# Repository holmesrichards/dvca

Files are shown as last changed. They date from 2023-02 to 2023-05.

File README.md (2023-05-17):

# MFOS Dual VCA

Kosmo format version of the [Music From Outer Space Dual VCA](http://musicfromouterspace.com/analogsynth_new/DUALVCA/DLLVCA001.html) synth module.

Circuit is basically unchanged from the original except:

* Eurorack style power header added, with reversal protection diodes
* Normal connection from 1st VCA output to 2nd VCA input

## Current draw
15 mA +12 V, 15 mA -12 V

## Photos

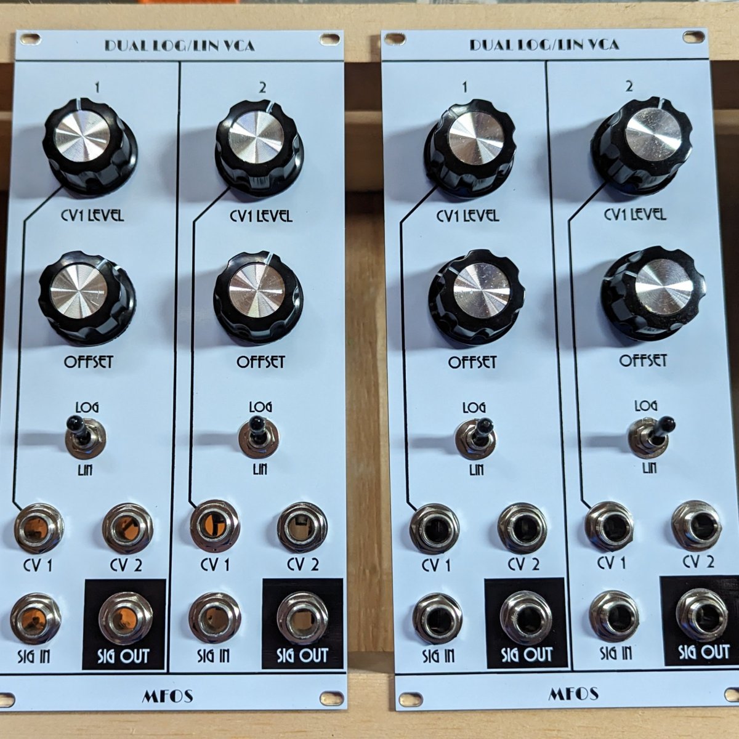
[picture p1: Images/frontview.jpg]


## Documentation

* [Schematic](Docs/dualvca_schematic.pdf)
* PCB layout: [front PCB front](Docs/Layout/dualvca_FrontPCB/dualvca_FrontPCB_front.svg), [front PCB back](Docs/Layout/dualvca_FrontPCB/dualvca_FrontPCB_back.svg), [back PCB front](Docs/Layout/dualvca_BackPCB/dualvca_BackPCB_front.svg), [back PCB back](Docs/Layout/dualvca_BackPCB/dualvca_BackPCB_back.svg)
* [BOM](Docs/BOM/dualvca_bom.md)
<!-- * [Build notes](Docs/build.md) -->
<!-- * [How it works](Docs/howitworks.md) -->
<!--* [Blog post]() -->

## GitHub repository

* [https://github.com/holmesrichards/dvca](https://github.com/holmesrichards/dvca)

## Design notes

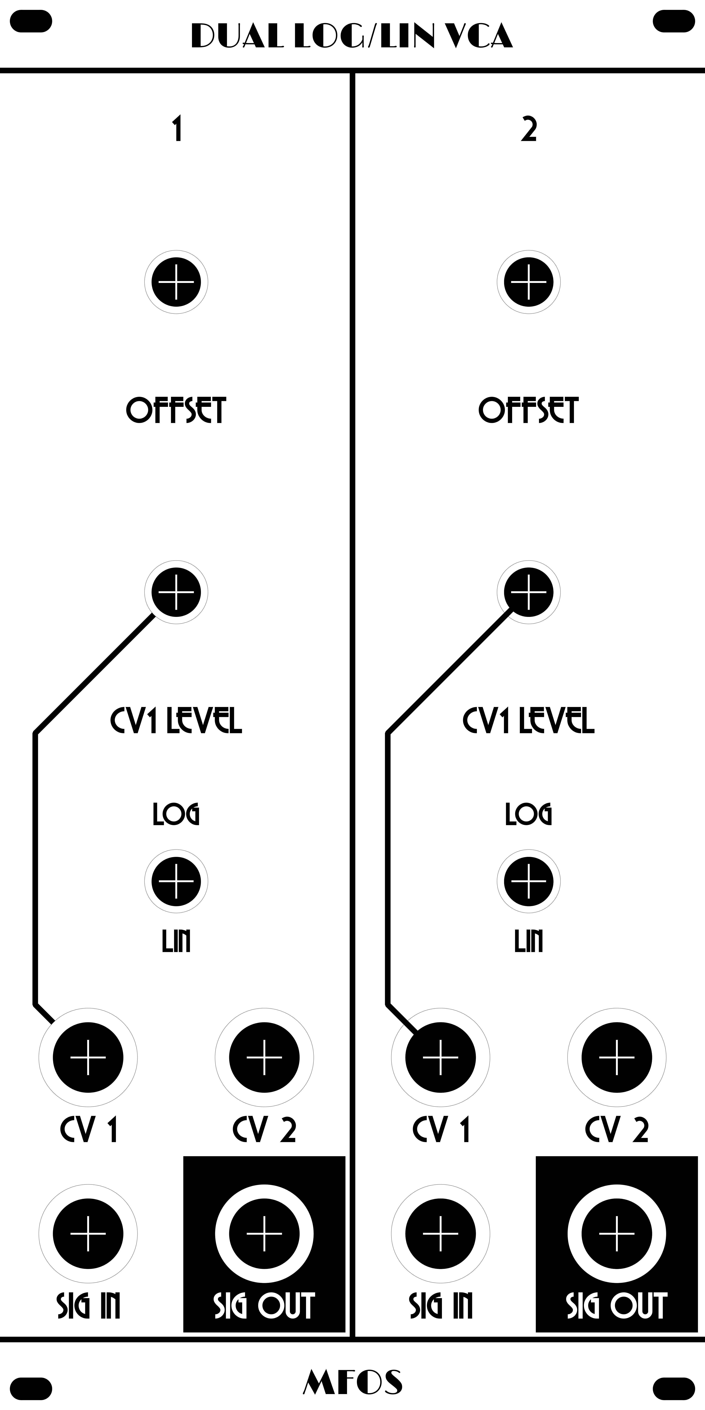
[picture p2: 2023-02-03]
Images/mfos_vca_panel_100_holes.png

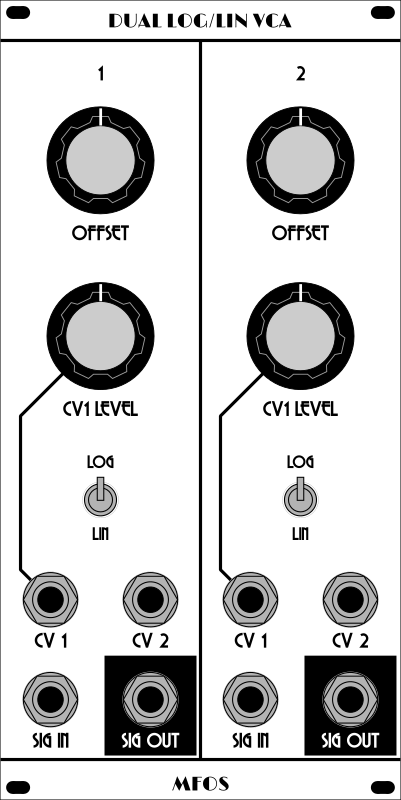
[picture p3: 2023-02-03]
Images/mfos_vca_panel_100.png

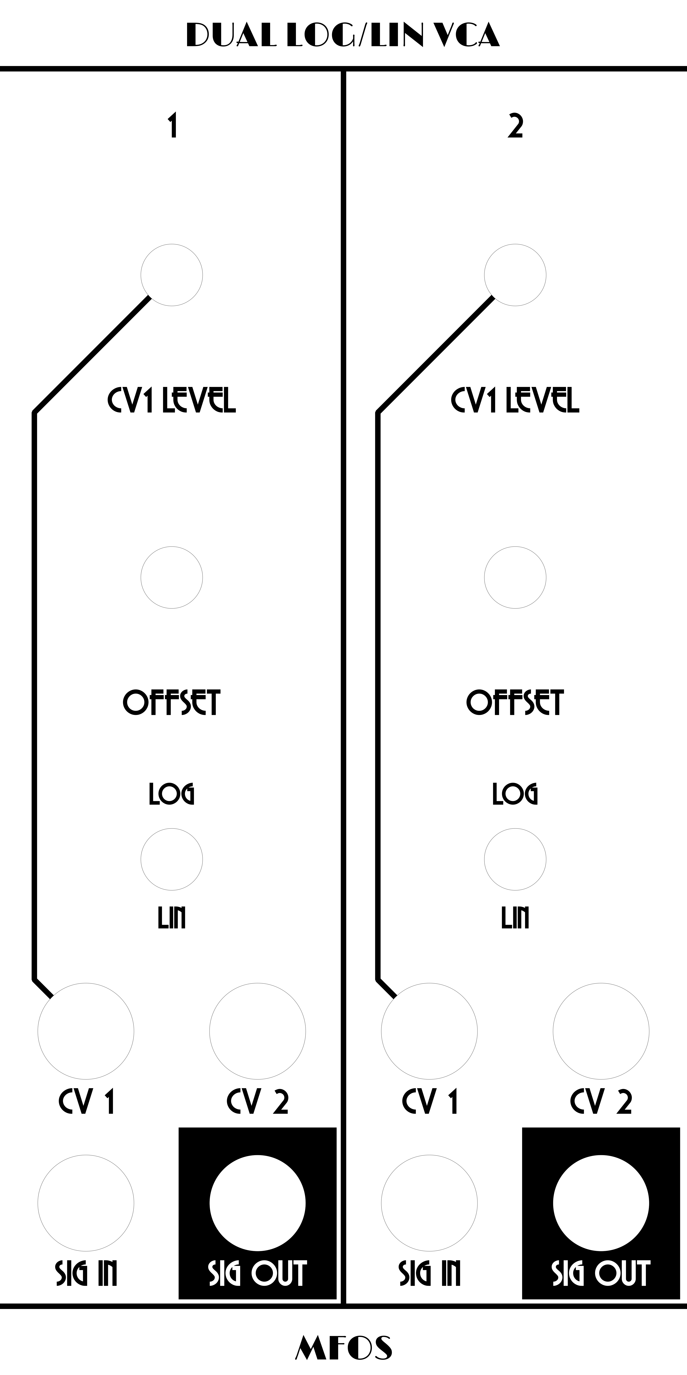
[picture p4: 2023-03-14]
Images/mfos_vca_panel_100_art.png

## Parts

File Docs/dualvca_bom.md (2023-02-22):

# dualvca.kicad_sch BOM

Tue 14 Feb 2023 09:02:56 PM EST

Generated from schematic by Eeschema 7.99.0-unknown-2cc3d8e9bc~165~ubuntu22.04.1

**Component Count:** 87

| Refs | Qty | Component | Description | Manufacturer | Part | Vendor | SKU |
| ----- | --- | ---- | --- | ---- | ---- | ---- | ---- |
| C1, C4 | 2 | 10uF | Electrolytic capacitor, 2.5 mm pitch |  |  | Tayda | A-4349 |
| C2, C3, C5, C6 | 4 | 100nF | Ceramic disc capacitor, 5 mm pitch |  |  | Tayda | A-553 |
| D101, D102 | 2 | 1N5817 | Schottky Barrier Rectifier Diode, DO-41 |  |  | Tayda | A-159 |
| J1, J2, J3, J4, J5, J6, J7 | 7 | AudioJack2 | Audio Jack, 2 Poles (Mono / TS) |  |  | Tayda | A-1121 |
| J8 | 1 | AudioJack2_SwitchT | Audio Jack, 2 Poles (Mono / TS), Switched T Pole (Normalling) |  |  | Tayda | A-1121 |
| J101 | 1 | Conn_01x15 | 2.54 mm pin header, 1x15 positions |  |  |  |  |
| J102 | 1 | Conn_01x15 | 2.54 mm pin socket, 1x15 positions |  |  |  |  |
| J103 | 1 | Synth_power_2x5 | Pin header 2.54 mm 2x5 |  |  | Tayda | A-2939 |
| J104 | 1 | DIP-14 | 14 pin DIP socket |  |  |  |  |
| J105 | 1 | DIP-16 | 16 pin DIP socket |  |  |  |  |
| Q1, Q3 | 2 | 2N3904 | Small Signal NPN Transistor, TO-92 |  |  | Tayda | A-111 |
| Q2, Q4 | 2 | 2N3906 | -0.2A Ic, -40V Vce, Small Signal PNP Transistor, TO-92 |  |  | Tayda | A-117 |
| R1, R2, R4, R5, R11, R13, R19, R23, R24, R26, R27, R33, R36, R40 | 14 | 100k | Resistor |  |  | Tayda |  |
| R3, R7, R25, R29, R37, R101 | 6 | 2k | Resistor |  |  | Tayda |  |
| R6, R28 | 2 | 470R | Resistor |  |  | Tayda |  |
| R8, R15, R30, R35 | 4 | 20k | Resistor |  |  | Tayda |  |
| R9, R31 | 2 | 30k | Resistor |  |  | Tayda |  |
| R14, R34 | 2 | 120k | Resistor |  |  | Tayda |  |
| R16, R38 | 2 | 4.7k | Resistor |  |  | Tayda |  |
| R17, R39 | 2 | 1k | Resistor |  |  | Tayda |  |
| R20, R42 | 2 | 150R | Resistor |  |  | Tayda |  |
| R21, R43 | 2 | 470k | Resistor |  |  | Tayda |  |
| R22, R44 | 2 | 47k | Resistor |  |  | Tayda |  |
| R46, R48 | 2 | 2M | Resistor |  |  | Tayda |  |
| RV10, RV32, RV101, RV102 | 4 | 100k | 9 mm board mount vertical pots (fit these *or* 16 mm) |  |  | Tayda |  |
| RV18, RV41, RV45, RV47 | 4 | 2k | Trim-potentiometer | Bourns | 3296W | Tayda |  |
| RV103, RV104, RV105, RV106 | 4 | 100k | 16 mm board mount vertical pots (fit these *or* 9 mm) |  |  | Tayda |  |
| SW1, SW2 | 2 | SW_SPDT | Switch, single pole double throw |  |  | Tayda | A-3186 |
| U1 | 1 | TL074 | Quad operational amplifier, DIP-14 |  |  | Tayda | A-1138 |
| U2 | 1 | LM13700 | Dual OTA, DIP-16 |  |  | Tayda | A-900 |
| ZKN101, ZKN102, ZKN103, ZKN104 | 4 | Knob_MF-A03 | MF-A03 knob |  |  |  |  |

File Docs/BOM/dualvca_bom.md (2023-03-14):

# dualvca.kicad_sch BOM

Mon 13 Mar 2023 09:42:59 PM EDT

Generated from schematic by Eeschema 7.0.1-3b83917a11~171~ubuntu22.04.1

**Component Count:** 87

| Refs | Qty | Component | Description | Manufacturer | Part | Vendor | SKU |
| ----- | --- | ---- | --- | ---- | ---- | ---- | ---- |
| C1, C4 | 2 | 10uF | Electrolytic capacitor, 2.5 mm pitch |  |  | Tayda | A-4349 |
| C2, C3, C5, C6 | 4 | 100nF | Ceramic disc capacitor, 5 mm pitch |  |  | Tayda | A-553 |
| D101, D102 | 2 | 1N5817 | Schottky Barrier Rectifier Diode, DO-41 |  |  | Tayda | A-159 |
| J1–7 | 7 | AudioJack2 | Audio Jack, 2 Poles (Mono / TS) |  |  | Tayda | A-1121 |
| J8 | 1 | AudioJack2_SwitchT | Audio Jack, 2 Poles (Mono / TS), Switched T Pole (Normalling) |  |  | Tayda | A-1121 |
| J101 | 1 | Conn_01x15 | 2.54 mm pin header, 1x15 positions |  |  |  |  |
| J102 | 1 | Conn_01x15 | 2.54 mm pin socket, 1x15 positions |  |  |  |  |
| J103 | 1 | Synth_power_2x5 | Pin header 2.54 mm 2x5 |  |  | Tayda | A-2939 |
| J104 | 1 | DIP-14 | 14 pin DIP socket |  |  |  |  |
| J105 | 1 | DIP-16 | 16 pin DIP socket |  |  |  |  |
| Q1, Q3 | 2 | 2N3904 | Small Signal NPN Transistor, TO-92 |  |  | Tayda | A-111 |
| Q2, Q4 | 2 | 2N3906 | -0.2A Ic, -40V Vce, Small Signal PNP Transistor, TO-92 |  |  | Tayda | A-117 |
| R1, R2, R4, R5, R11, R13, R19, R23, R24, R26, R27, R33, R36, R40 | 14 | 100k | Resistor |  |  | Tayda |  |
| R3, R7, R25, R29, R37, R101 | 6 | 2k | Resistor |  |  | Tayda |  |
| R6, R28 | 2 | 470R | Resistor |  |  | Tayda |  |
| R8, R15, R30, R35 | 4 | 20k | Resistor |  |  | Tayda |  |
| R9, R31 | 2 | 30k | Resistor |  |  | Tayda |  |
| R14, R34 | 2 | 120k | Resistor |  |  | Tayda |  |
| R16, R38 | 2 | 4.7k | Resistor |  |  | Tayda |  |
| R17, R39 | 2 | 1k | Resistor |  |  | Tayda |  |
| R20, R42 | 2 | 150R | Resistor |  |  | Tayda |  |
| R21, R43 | 2 | 470k | Resistor |  |  | Tayda |  |
| R22, R44 | 2 | 47k | Resistor |  |  | Tayda |  |
| R46, R48 | 2 | 2M | Resistor |  |  | Tayda |  |
| RV10, RV32, RV101, RV102 | 4 | 100k | 9 mm board mount vertical pots (fit these *or* 16 mm) |  |  | Tayda |  |
| RV18, RV41, RV45, RV47 | 4 | 2k | Trim-potentiometer | Bourns | 3296W | Tayda |  |
| RV103–106 | 4 | 100k | 16 mm board mount vertical pots (fit these *or* 9 mm) |  |  | Tayda |  |
| SW1, SW2 | 2 | SW_SPDT | Switch, single pole double throw |  |  | Tayda | A-3186 |
| U1 | 1 | TL074 | Quad operational amplifier, DIP-14 |  |  | Tayda | A-1138 |
| U2 | 1 | LM13700 | Dual OTA, DIP-16 |  |  | Tayda | A-900 |
| ZKN101–104 | 4 | Knob_MF-A03 | MF-A03 knob |  |  |  |  |

## Resistors in color band order
|Value|Qty|Refs|
|----|----|----|
|1k|2|R17, R39|
|100k|14|R1, R2, R4, R5, R11, R13, R19, R23, R24, R26, R27, R33, R36, R40|
|120k|2|R14, R34|
|150R|2|R20, R42|
|2k|6|R3, R7, R25, R29, R37, R101|
|20k|4|R8, R15, R30, R35|
|2M|2|R46, R48|
|30k|2|R9, R31|
|470R|2|R6, R28|
|4.7k|2|R16, R38|
|47k|2|R22, R44|
|470k|2|R21, R43|

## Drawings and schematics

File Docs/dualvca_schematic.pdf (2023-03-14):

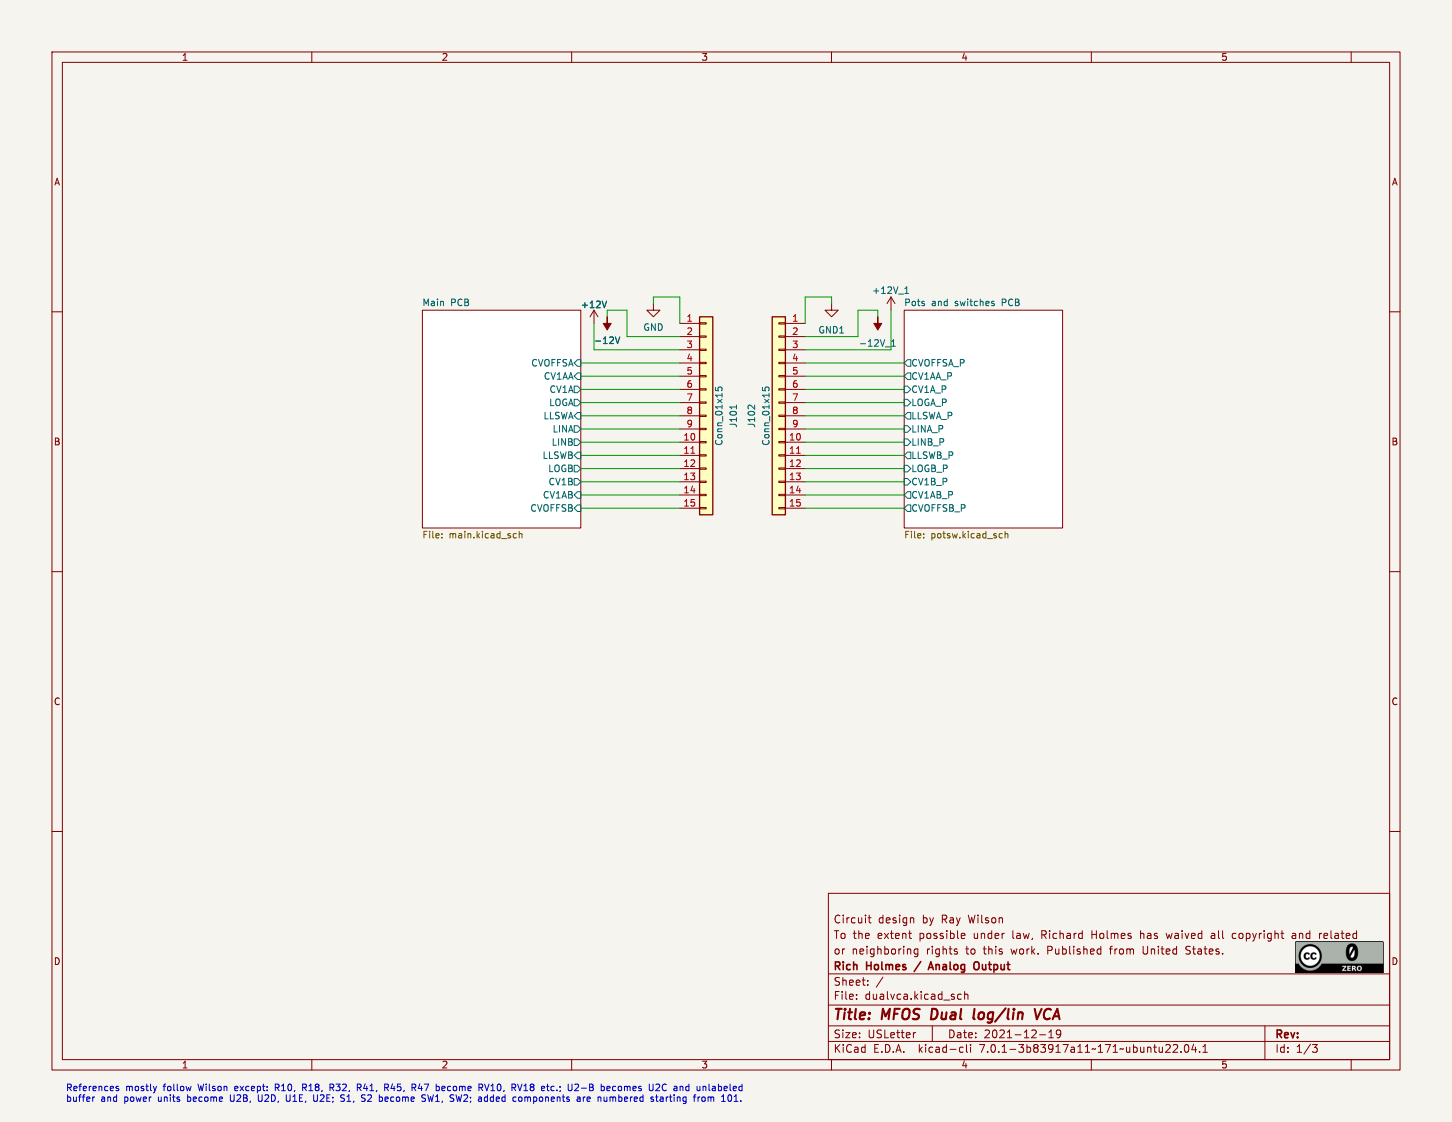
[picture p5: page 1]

LLSWA CV1B CVOFFSB CV1AB CV1AA CV1A CVOFFSA Main PCB

Pots and switches PCB
LINB_P CV1B_P CV1AB_P CV1AA_P CV1A_P CVOFFSA_P

References mostly follow Wilson except: R10, R18, R32, R41, R45, R47 become RV10, RV18 etc.; U2-B becomes U2C and unlabeled

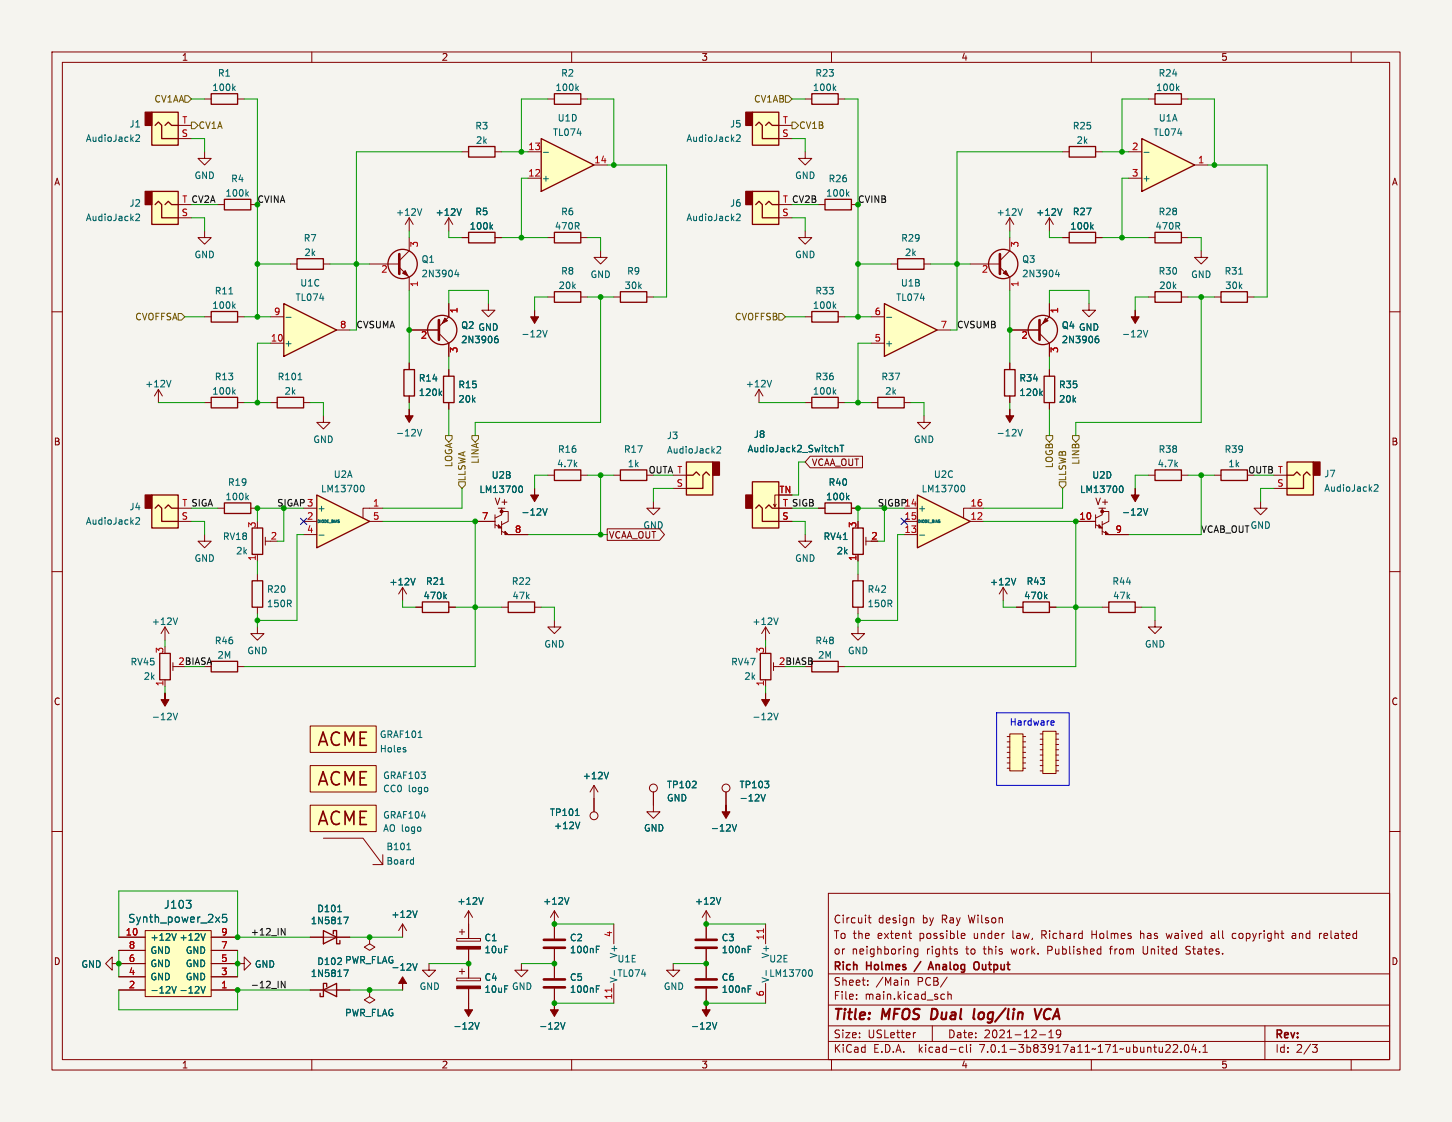
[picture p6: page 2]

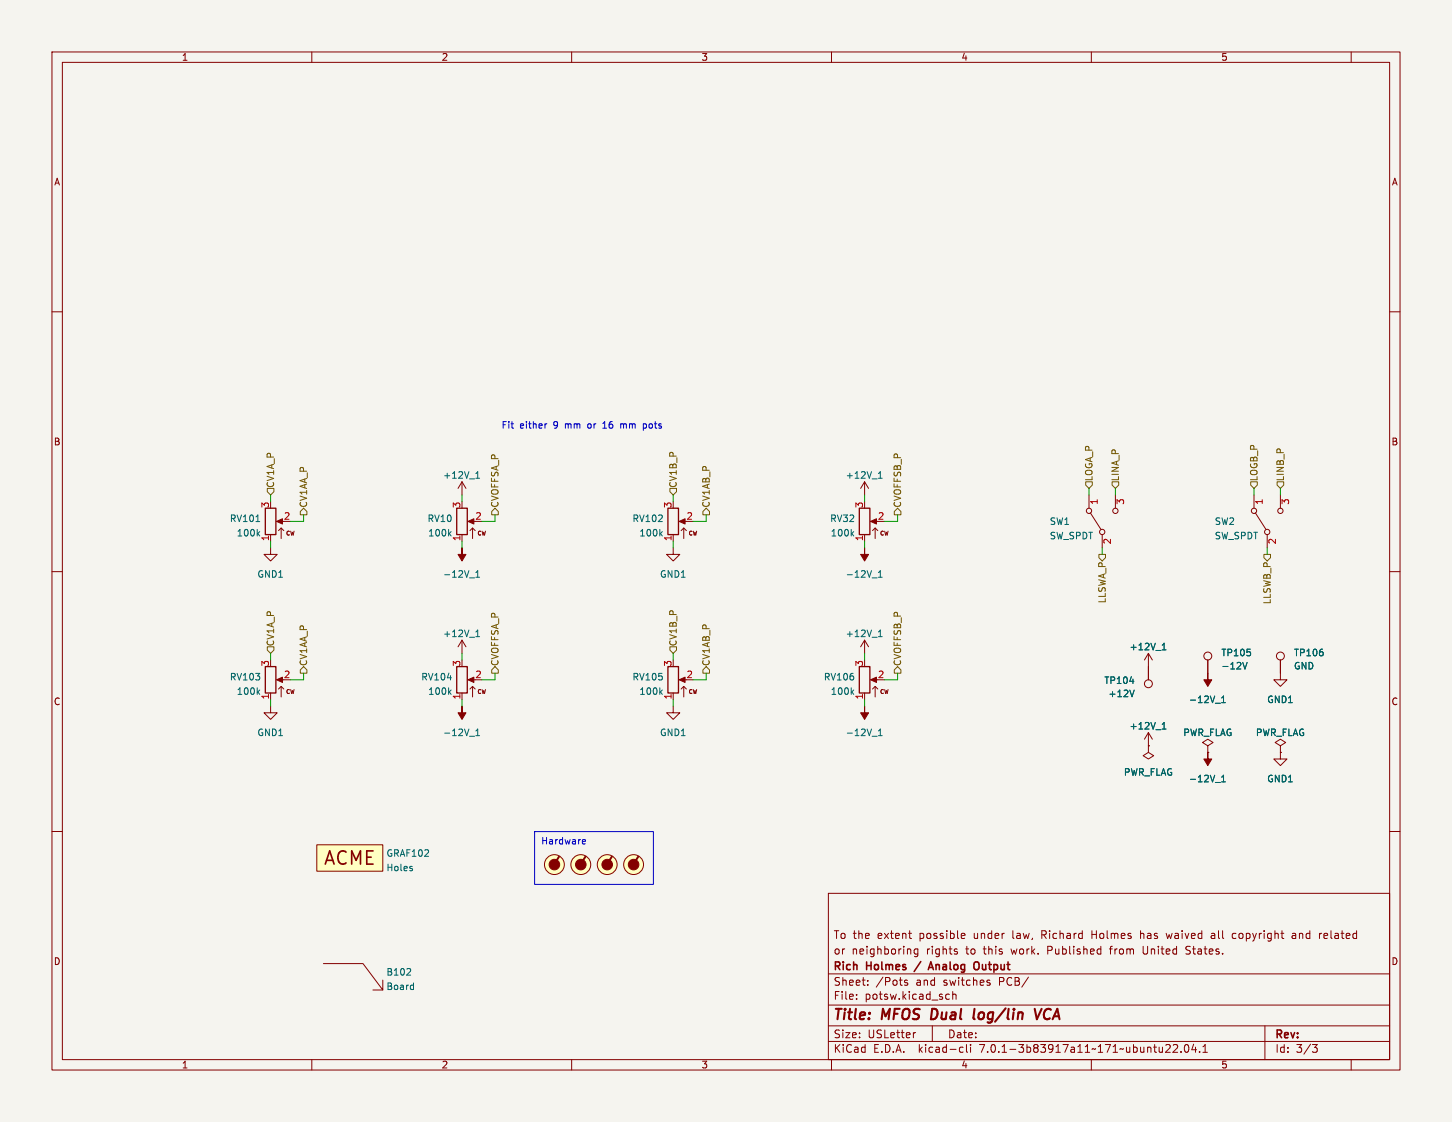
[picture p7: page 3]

Fit either 9 mm or 16 mm pots

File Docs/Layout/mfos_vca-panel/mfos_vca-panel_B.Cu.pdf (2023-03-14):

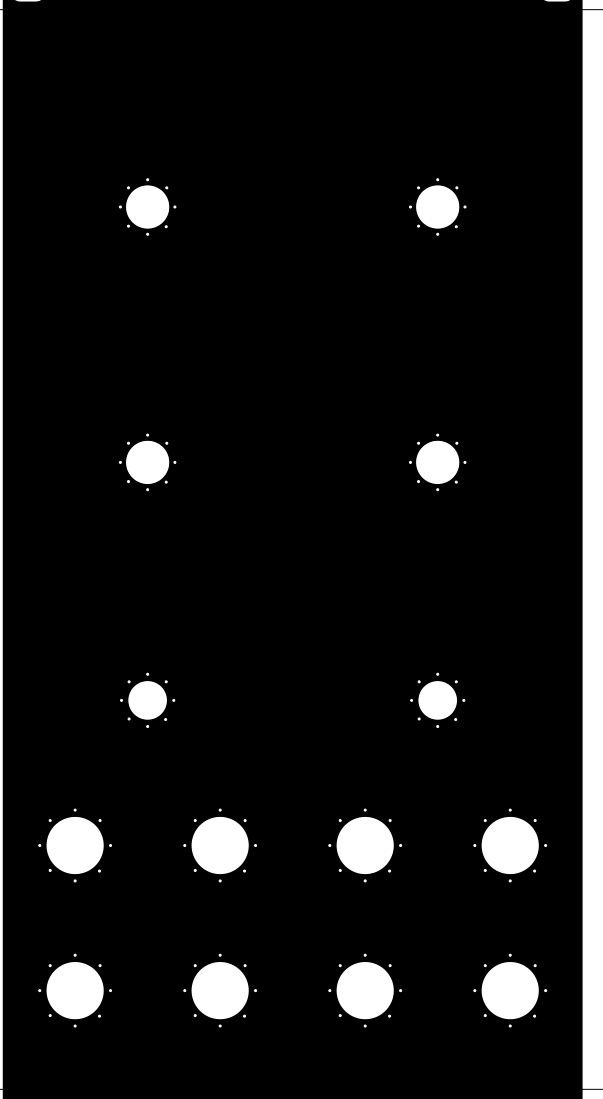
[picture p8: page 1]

Id: 1/1 Title: File: mfos_vca-panel.kicad_pcb Sheet:

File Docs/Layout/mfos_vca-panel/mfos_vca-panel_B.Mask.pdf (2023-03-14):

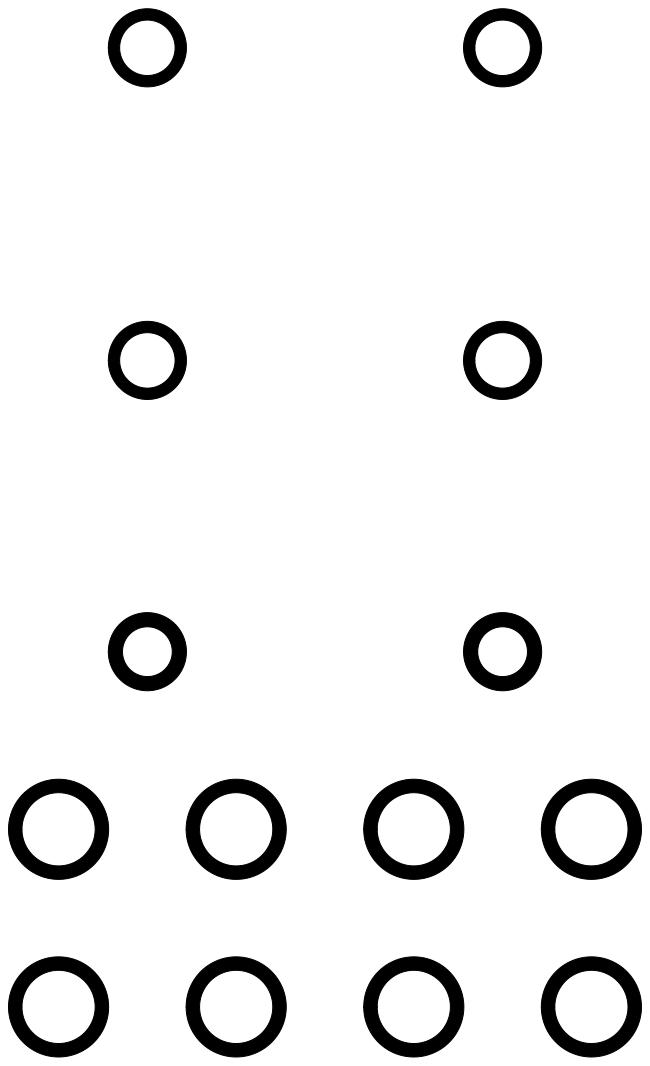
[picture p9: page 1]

Id: 1/1 Title: File: mfos_vca-panel.kicad_pcb Sheet:

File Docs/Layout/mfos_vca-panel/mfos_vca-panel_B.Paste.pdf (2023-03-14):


Id: 1/1 Title: File: mfos_vca-panel.kicad_pcb Sheet:

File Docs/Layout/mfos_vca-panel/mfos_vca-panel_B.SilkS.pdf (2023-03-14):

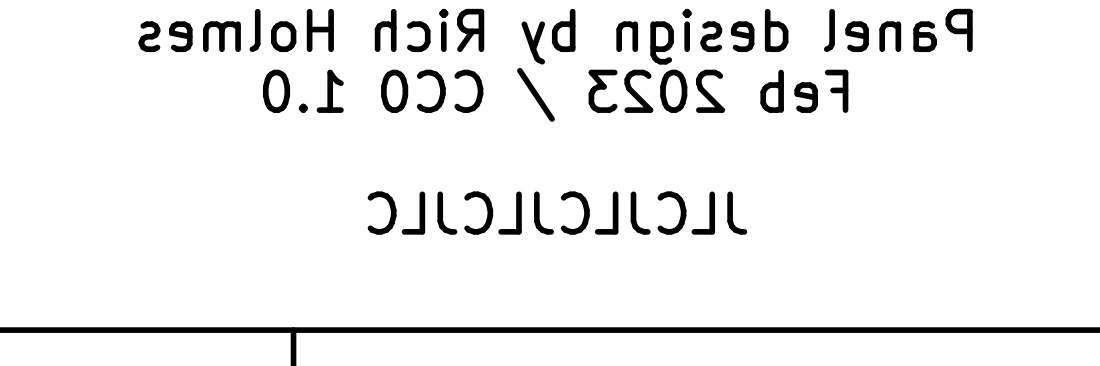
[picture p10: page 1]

Id: 1/1 Title: File: mfos_vca-panel.kicad_pcb Sheet: Panel design by Rich Holmes Feb 2023 / CC0 1.0

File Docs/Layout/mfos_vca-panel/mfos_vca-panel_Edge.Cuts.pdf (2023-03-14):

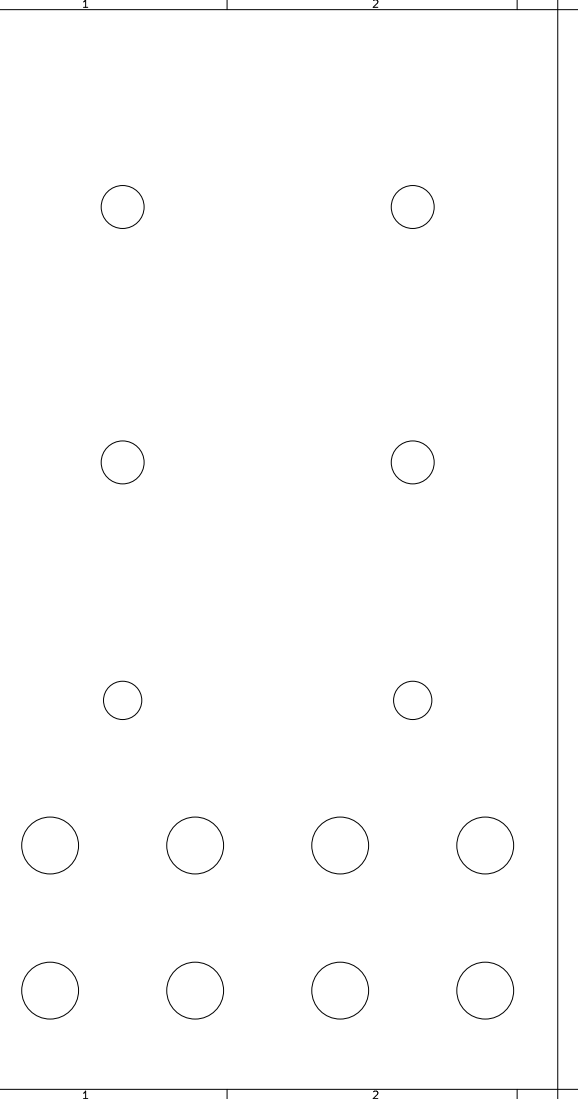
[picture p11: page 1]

Id: 1/1 Title: File: mfos_vca-panel.kicad_pcb Sheet:

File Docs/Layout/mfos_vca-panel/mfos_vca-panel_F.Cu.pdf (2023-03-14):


Id: 1/1 Title: File: mfos_vca-panel.kicad_pcb Sheet:

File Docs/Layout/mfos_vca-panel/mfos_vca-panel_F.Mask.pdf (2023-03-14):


Id: 1/1 Title: File: mfos_vca-panel.kicad_pcb Sheet:

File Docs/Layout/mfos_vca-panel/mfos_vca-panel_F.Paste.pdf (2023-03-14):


Id: 1/1 Title: File: mfos_vca-panel.kicad_pcb Sheet:

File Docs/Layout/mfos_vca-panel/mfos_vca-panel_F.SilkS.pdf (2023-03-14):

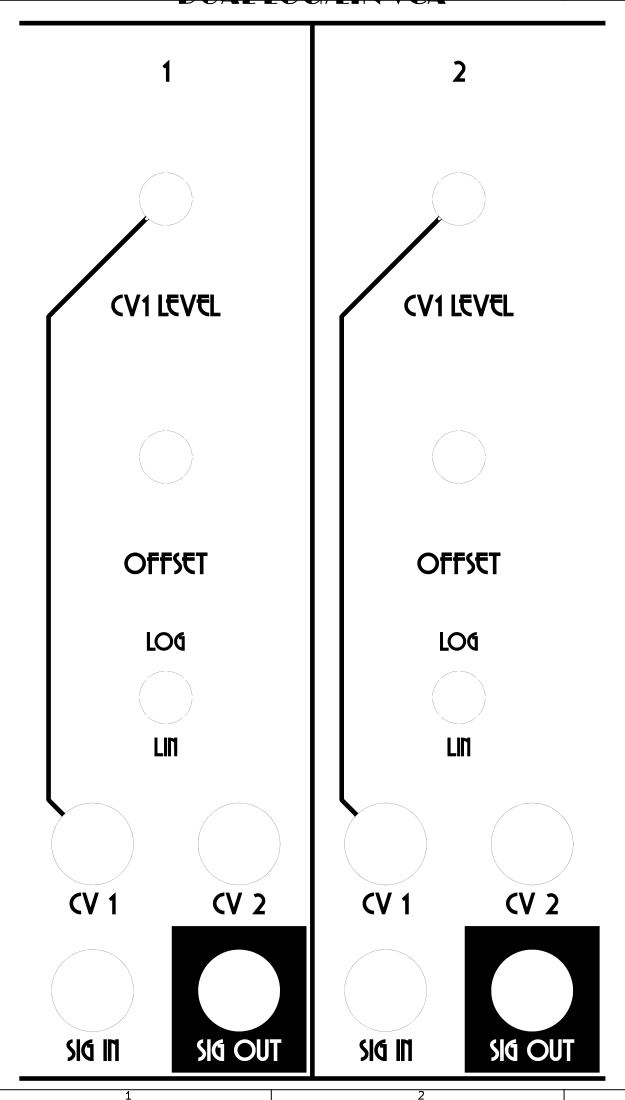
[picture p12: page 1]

Id: 1/1 Title: File: mfos_vca-panel.kicad_pcb Sheet:

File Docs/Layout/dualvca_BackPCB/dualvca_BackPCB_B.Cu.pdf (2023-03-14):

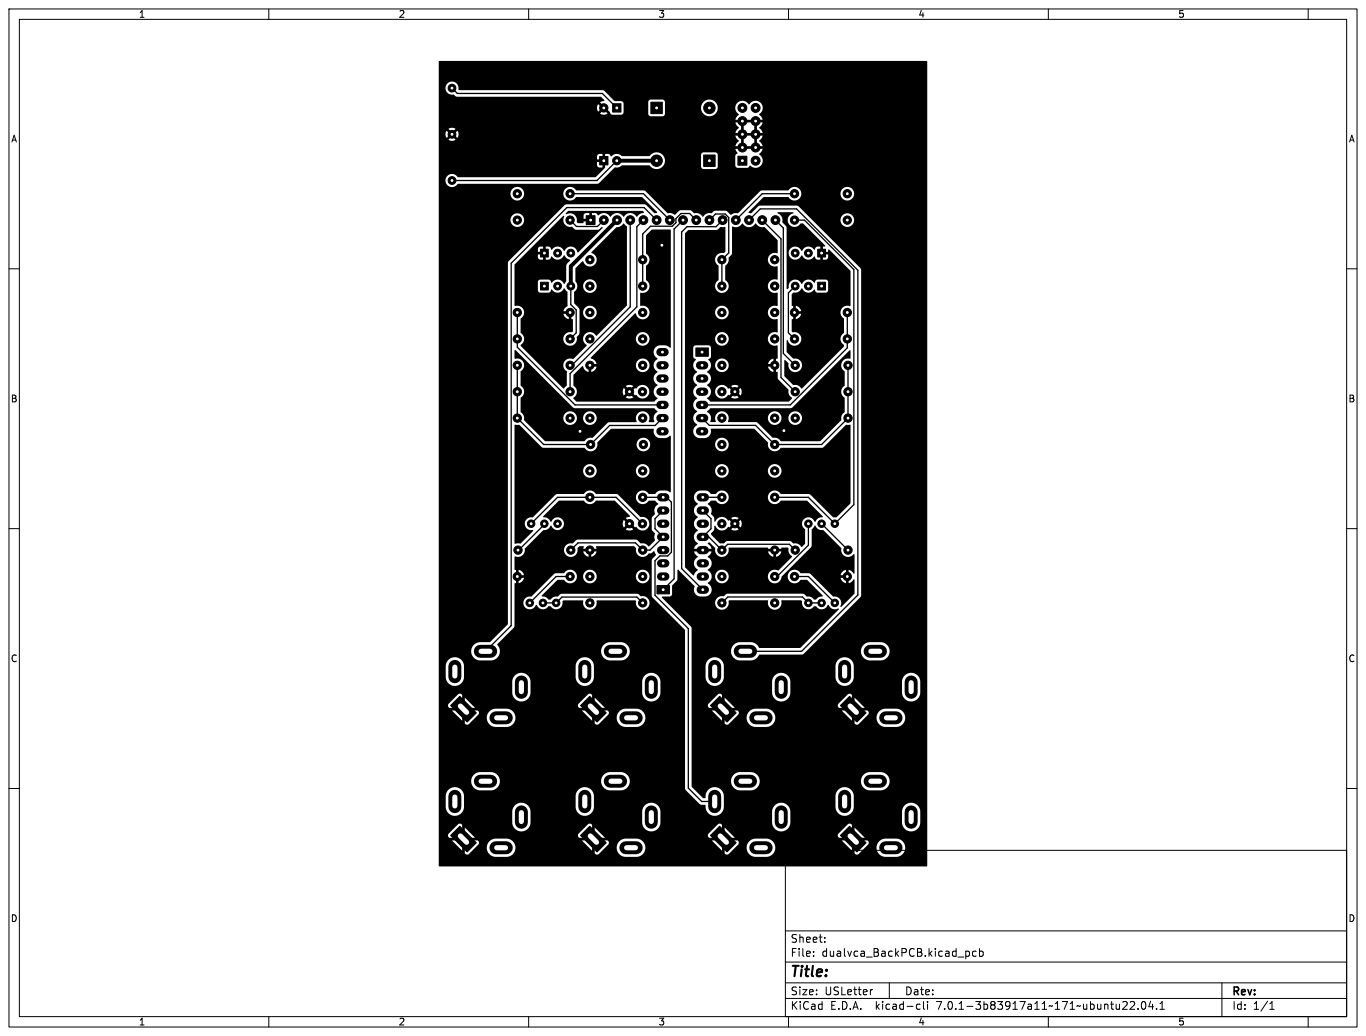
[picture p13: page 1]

Id: 1/1 Title: File: dualvca_BackPCB.kicad_pcb Sheet:

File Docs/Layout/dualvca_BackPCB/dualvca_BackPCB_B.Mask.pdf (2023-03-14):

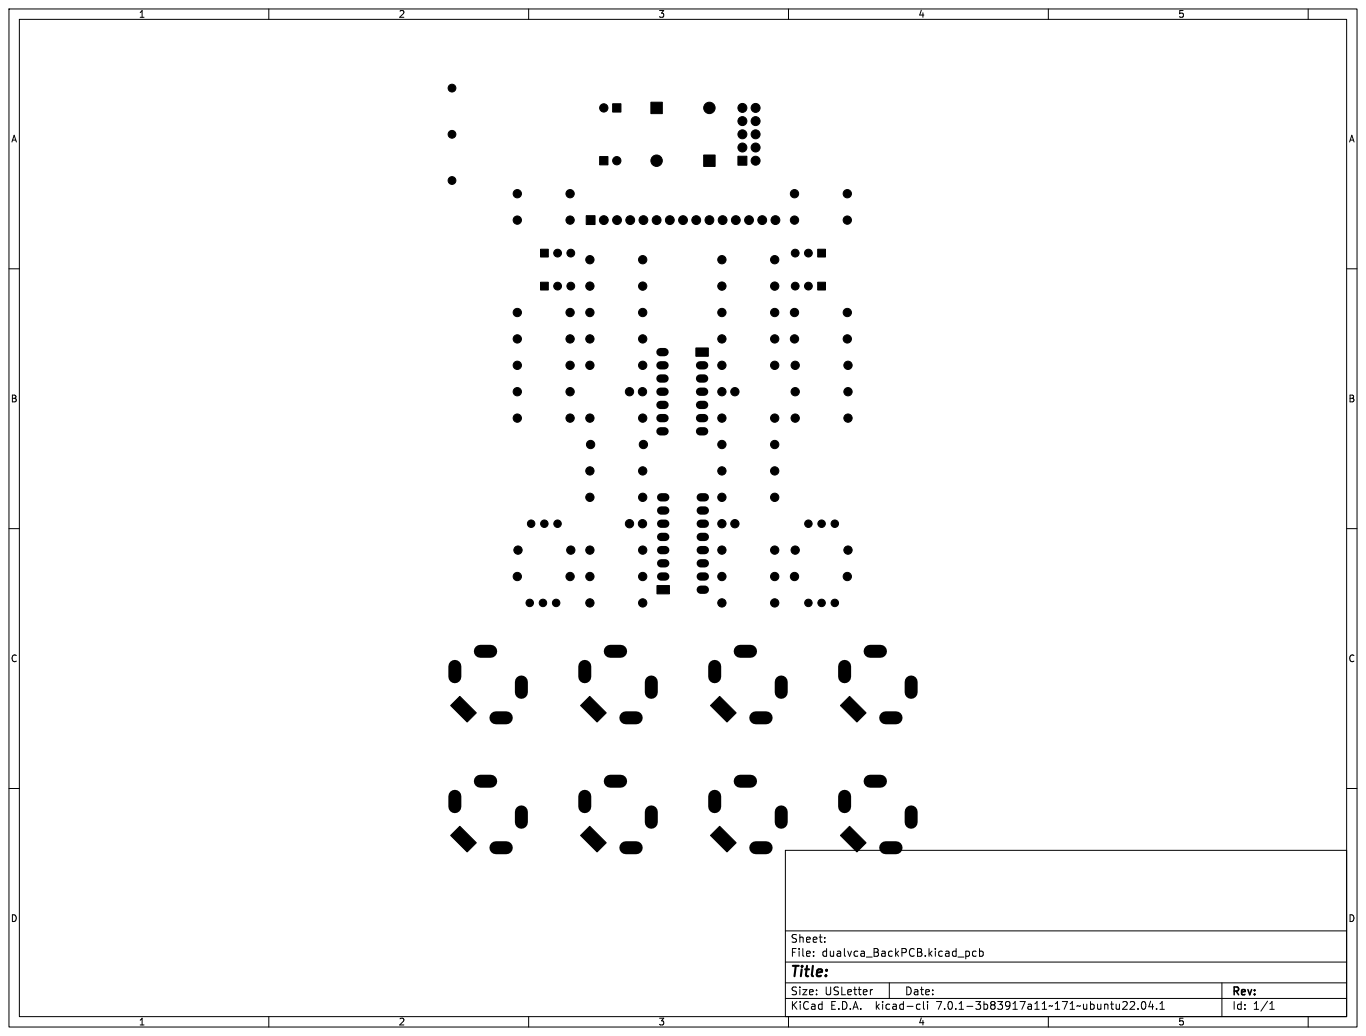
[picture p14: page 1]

Id: 1/1 Title: File: dualvca_BackPCB.kicad_pcb Sheet:

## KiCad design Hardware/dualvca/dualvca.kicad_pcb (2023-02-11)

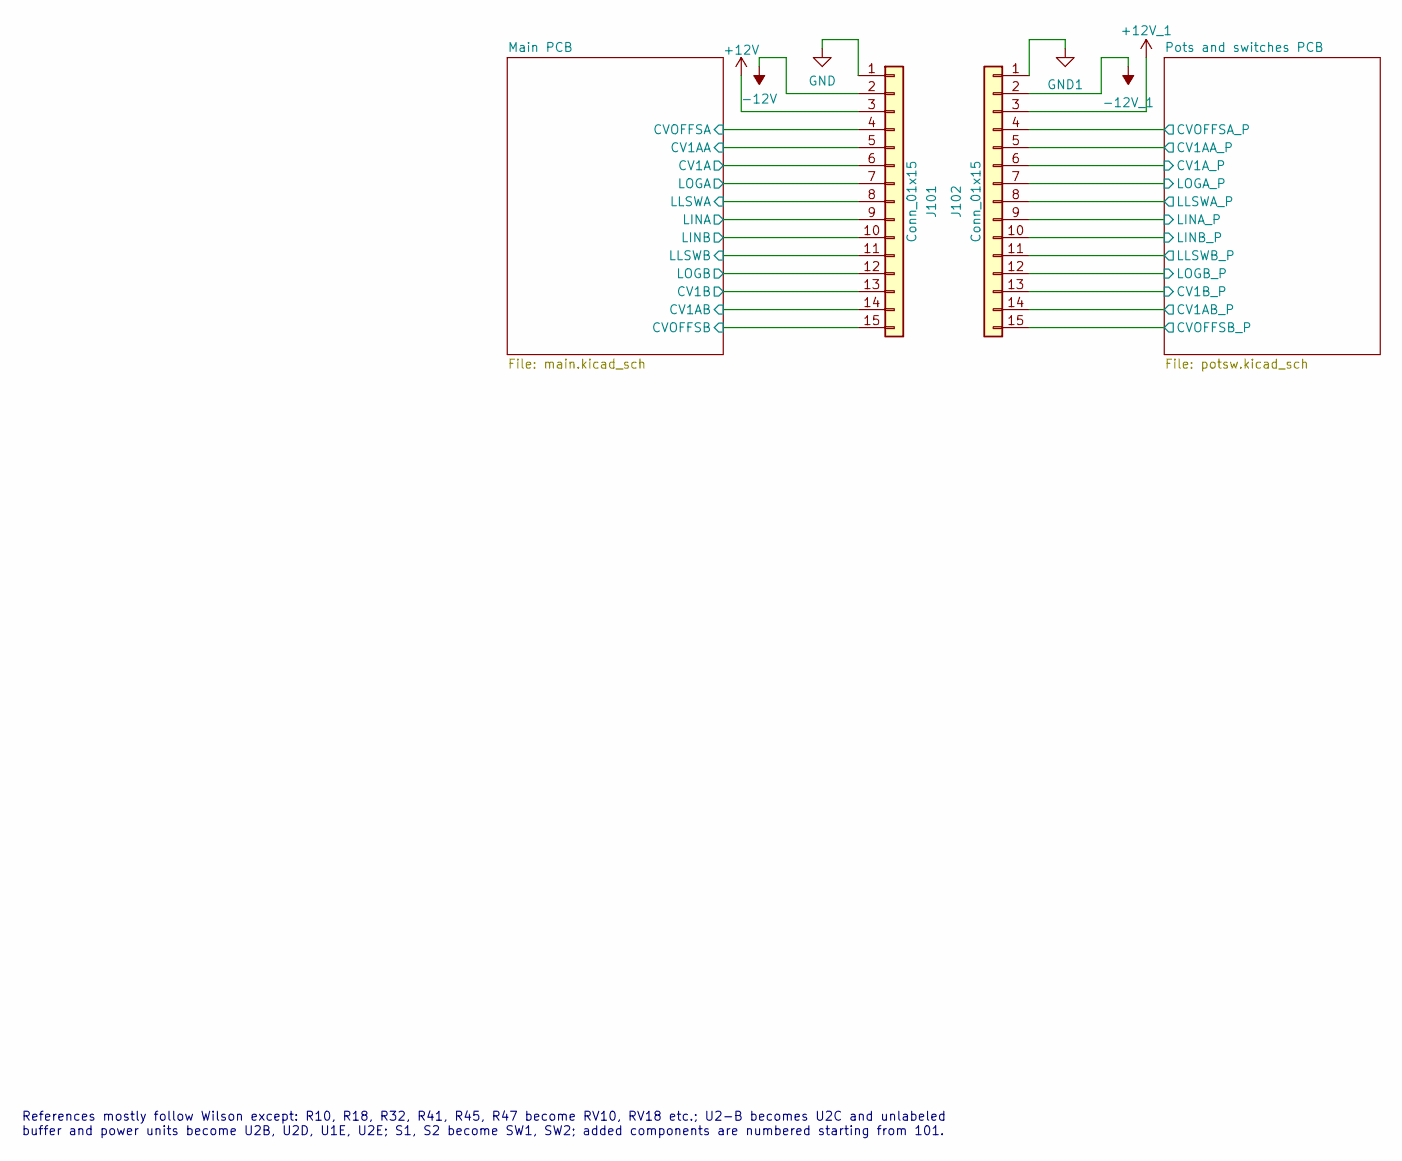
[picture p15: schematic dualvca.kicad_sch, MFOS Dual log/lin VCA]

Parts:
J101: Conn_01x15; PinHeader_1x15_P2.54mm_Vertical
J102: Conn_01x15; PinSocket_1x15_P2.54mm_Vertical

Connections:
+12V: J101.3; also elsewhere on the board
+12V_1: J102.3; also elsewhere on the board
-12V: J101.2; also elsewhere on the board
-12V_1: J102.2; also elsewhere on the board
/Main PCB/CV1A: J101.6; also elsewhere on the board
/Main PCB/CV1AA: J101.5; also elsewhere on the board
/Main PCB/CV1AB: J101.14; also elsewhere on the board
/Main PCB/CV1B: J101.13; also elsewhere on the board
/Main PCB/CVOFFSA: J101.4; also elsewhere on the board
/Main PCB/CVOFFSB: J101.15; also elsewhere on the board
/Main PCB/LINA: J101.9; also elsewhere on the board
/Main PCB/LINB: J101.10; also elsewhere on the board
/Main PCB/LLSWA: J101.8; also elsewhere on the board
/Main PCB/LLSWB: J101.11; also elsewhere on the board
/Main PCB/LOGA: J101.7; also elsewhere on the board
/Main PCB/LOGB: J101.12; also elsewhere on the board
/Pots and switches PCB/CV1AA_P: J102.5; also elsewhere on the board
/Pots and switches PCB/CV1AB_P: J102.14; also elsewhere on the board
/Pots and switches PCB/CV1A_P: J102.6; also elsewhere on the board
/Pots and switches PCB/CV1B_P: J102.13; also elsewhere on the board
/Pots and switches PCB/CVOFFSA_P: J102.4; also elsewhere on the board
/Pots and switches PCB/CVOFFSB_P: J102.15; also elsewhere on the board
/Pots and switches PCB/LINA_P: J102.9; also elsewhere on the board
/Pots and switches PCB/LINB_P: J102.10; also elsewhere on the board
/Pots and switches PCB/LLSWA_P: J102.8; also elsewhere on the board
/Pots and switches PCB/LLSWB_P: J102.11; also elsewhere on the board
/Pots and switches PCB/LOGA_P: J102.7; also elsewhere on the board
/Pots and switches PCB/LOGB_P: J102.12; also elsewhere on the board
GND: J101.1; also elsewhere on the board
GND1: J102.1; also elsewhere on the board

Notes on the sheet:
References mostly follow Wilson except: R10, R18, R32, R41, R45, R47 become RV10, RV18 etc.; U2-B becomes U2C and unlabeled buffer and power units become U2B, U2D, U1E, U2E; S1, S2 become SW1, SW2; added components are numbered starting from 101.

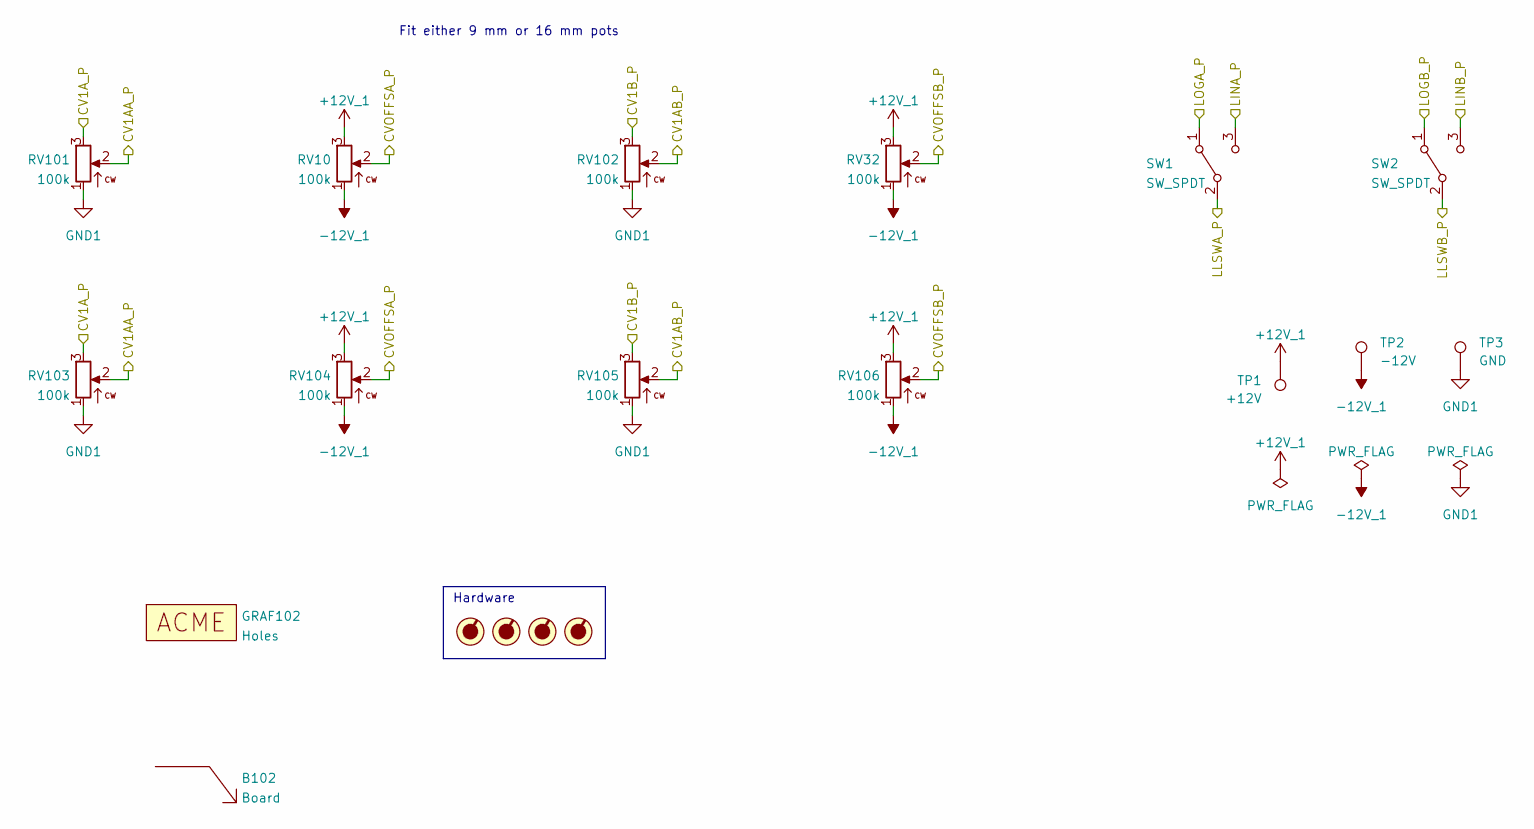
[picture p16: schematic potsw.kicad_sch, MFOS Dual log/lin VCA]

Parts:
B102: Board; Board_Marker
GRAF102: Holes; mfos_vca_panel_100_holes
RV10, RV32, RV101, RV102: 100k; Potentiometer_Alpha_RD901F-40-00D_Single_Vertical_centered
RV103, RV104, RV105, RV106: 100k; Potentiometer_Alpha_16mm_Single_Vertical
SW1, SW2: SW_SPDT; SPDT-toggle-switch-1M-series
TP1: +12V; TestPoint_THTPad_D1.5mm_Drill0.7mm
TP2: -12V; TestPoint_THTPad_D1.5mm_Drill0.7mm
TP3: GND; TestPoint_THTPad_D1.5mm_Drill0.7mm
ZKN101, ZKN102, ZKN103, ZKN104: Knob_MF-A03

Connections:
+12V_1: RV10.3, RV32.3, RV104.3, RV106.3; also elsewhere on the board
-12V_1: RV10.1, RV32.1, RV104.1, RV106.1; also elsewhere on the board
/Pots and switches PCB/CV1AA_P: RV101.2, RV103.2; also elsewhere on the board
/Pots and switches PCB/CV1AB_P: RV102.2, RV105.2; also elsewhere on the board
/Pots and switches PCB/CV1A_P: RV101.3, RV103.3; also elsewhere on the board
/Pots and switches PCB/CV1B_P: RV102.3, RV105.3; also elsewhere on the board
/Pots and switches PCB/CVOFFSA_P: RV10.2, RV104.2; also elsewhere on the board
/Pots and switches PCB/CVOFFSB_P: RV32.2, RV106.2; also elsewhere on the board
/Pots and switches PCB/LINA_P: SW1.3 (C); also elsewhere on the board
/Pots and switches PCB/LINB_P: SW2.3 (C); also elsewhere on the board
/Pots and switches PCB/LLSWA_P: SW1.2 (B); also elsewhere on the board
/Pots and switches PCB/LLSWB_P: SW2.2 (B); also elsewhere on the board
/Pots and switches PCB/LOGA_P: SW1.1 (A); also elsewhere on the board
/Pots and switches PCB/LOGB_P: SW2.1 (A); also elsewhere on the board
GND1: RV101.1, RV102.1, RV103.1, RV105.1; also elsewhere on the board

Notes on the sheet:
Fit either 9 mm or 16 mm pots
Hardware

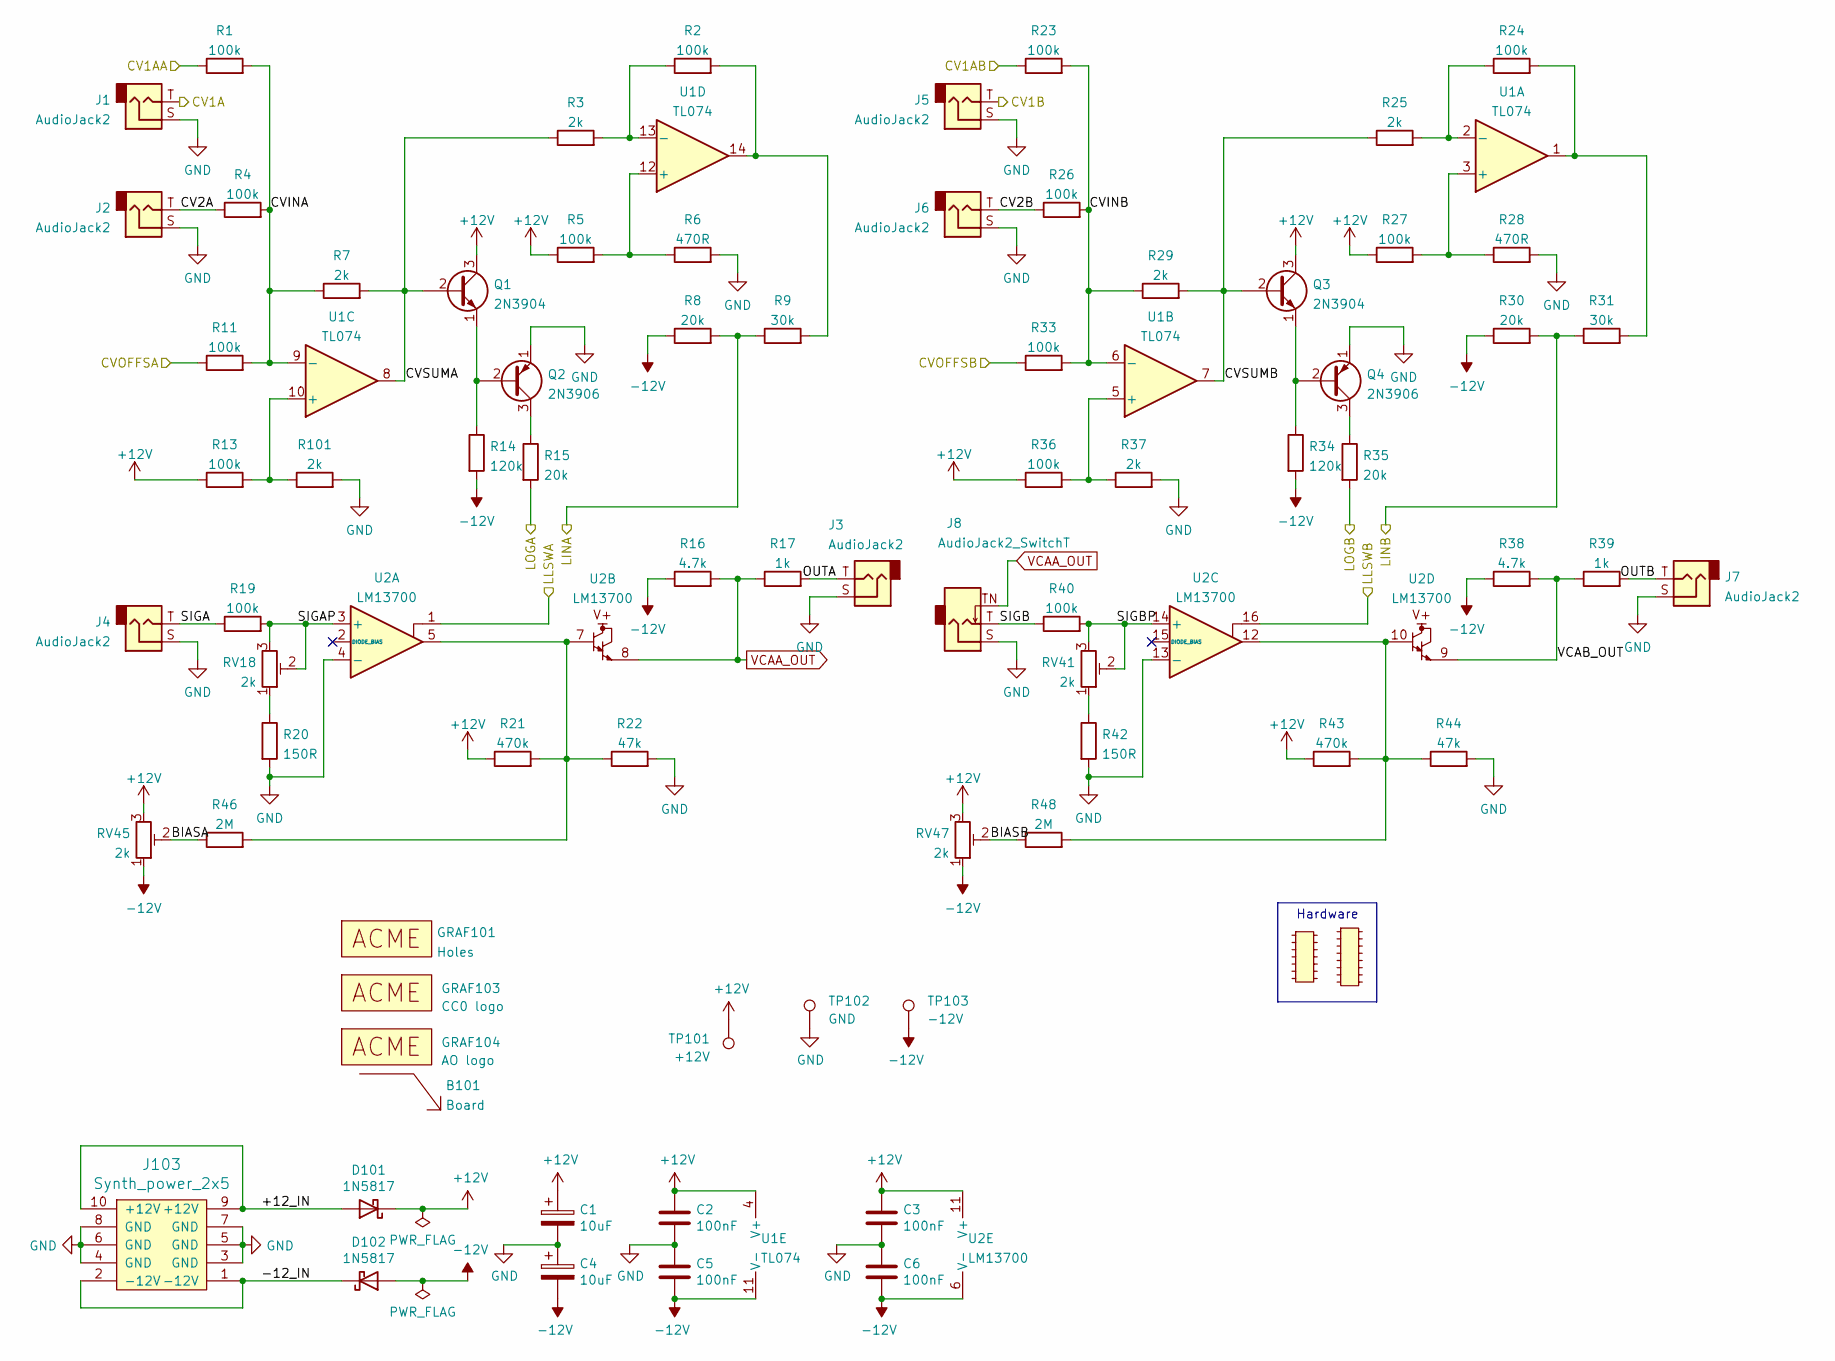
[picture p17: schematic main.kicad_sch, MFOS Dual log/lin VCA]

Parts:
B101: Board; Board_Marker
C1, C4: 10uF; CP_Radial_D6.3mm_P2.50mm
C2, C3, C5, C6: 100nF; C_Disc_D3.0mm_W1.6mm_P2.50mm
D101, D102: 1N5817; D_DO-41_SOD81_P10.16mm_Horizontal
GRAF101: Holes; mfos_vca_panel_100_holes
GRAF103: CC0 logo; CC0_logo
GRAF104: AO logo; analogoutput
J1, J2, J3, J4, J5, J6, J7: AudioJack2; Jack_6.35mm_PJ_629HAN_slots
J8: AudioJack2_SwitchT; Jack_6.35mm_PJ_629HAN_slots
J103: Synth_power_2x5; Power_Header
J104: DIP-14
J105: DIP-16
Q1, Q3: 2N3904; TO-92_Inline_Wide
Q2, Q4: 2N3906; TO-92_Inline_Wide
R1, R2, R4, R5, R11, R13, R19, R23, R24, R26, R27, R33, R36, R40: 100k; R_Axial_DIN0207_L6.3mm_D2.5mm_P10.16mm_Horizontal
R3, R7, R25, R29, R37, R101: 2k; R_Axial_DIN0207_L6.3mm_D2.5mm_P10.16mm_Horizontal
R6, R28: 470R; R_Axial_DIN0207_L6.3mm_D2.5mm_P10.16mm_Horizontal
R8, R15, R30, R35: 20k; R_Axial_DIN0207_L6.3mm_D2.5mm_P10.16mm_Horizontal
R9, R31: 30k; R_Axial_DIN0207_L6.3mm_D2.5mm_P10.16mm_Horizontal
R14, R34: 120k; R_Axial_DIN0207_L6.3mm_D2.5mm_P10.16mm_Horizontal
R16, R38: 4.7k; R_Axial_DIN0207_L6.3mm_D2.5mm_P10.16mm_Horizontal
R17, R39: 1k; R_Axial_DIN0207_L6.3mm_D2.5mm_P10.16mm_Horizontal
R20, R42: 150R; R_Axial_DIN0207_L6.3mm_D2.5mm_P10.16mm_Horizontal
R21, R43: 470k; R_Axial_DIN0207_L6.3mm_D2.5mm_P10.16mm_Horizontal
R22, R44: 47k; R_Axial_DIN0207_L6.3mm_D2.5mm_P10.16mm_Horizontal
R46, R48: 2M; R_Axial_DIN0207_L6.3mm_D2.5mm_P10.16mm_Horizontal
RV18, RV41, RV45, RV47: 2k; Potentiometer_Bourns_3296W_Vertical_standard; Part 3296W
TP101: +12V; TestPoint_THTPad_D1.5mm_Drill0.7mm
TP102: GND; TestPoint_THTPad_D1.5mm_Drill0.7mm
TP103: -12V; TestPoint_THTPad_D1.5mm_Drill0.7mm
U1: TL074; DIP-14_W7.62mm_Socket_LongPads
U2: LM13700; DIP-16_W7.62mm_Socket_LongPads

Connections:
+12V: C1.1, C2.1, C3.1, D101.1 (K), Q1.3 (C), Q3.3 (C), R5.1, R13.1, R21.1, R27.1, R36.1, R43.1, RV45.3, RV47.3, TP101.1, U1.4 (V+), U2.11 (V+); also elsewhere on the board
-12V: C4.2, C5.2, C6.2, D102.2 (A), R8.1, R14.2, R16.1, R30.1, R34.2, R38.1, RV45.1, RV47.1, TP103.1, U1.11 (V-), U2.6 (V-); also elsewhere on the board
/Main PCB/+12_IN: D101.2 (A), J103.9 (+12V), J103.10 (+12V)
/Main PCB/-12_IN: D102.1 (K), J103.1 (-12V), J103.2 (-12V)
/Main PCB/BIASA: R46.1, RV45.2
/Main PCB/BIASB: R48.1, RV47.2
/Main PCB/CV1A: J1.T; also elsewhere on the board
/Main PCB/CV1AA: R1.1; also elsewhere on the board
/Main PCB/CV1AB: R23.1; also elsewhere on the board
/Main PCB/CV1B: J5.T; also elsewhere on the board
/Main PCB/CV2A: J2.T, R4.1
/Main PCB/CV2B: J6.T, R26.1
/Main PCB/CVINA: R1.2, R4.2, R7.1, R11.2, U1.9 (-)
/Main PCB/CVINB: R23.2, R26.2, R29.1, R33.2, U1.6 (-)
/Main PCB/CVOFFSA: R11.1; also elsewhere on the board
/Main PCB/CVOFFSB: R33.1; also elsewhere on the board
/Main PCB/CVSUMA: Q1.2 (B), R3.1, R7.2, U1.8
/Main PCB/CVSUMB: Q3.2 (B), R25.1, R29.2, U1.7
/Main PCB/LINA: R8.2, R9.1; also elsewhere on the board
/Main PCB/LINB: R30.2, R31.1; also elsewhere on the board
/Main PCB/LLSWA: U2.1; also elsewhere on the board
/Main PCB/LLSWB: U2.16; also elsewhere on the board
/Main PCB/LOGA: R15.2; also elsewhere on the board
/Main PCB/LOGB: R35.2; also elsewhere on the board
/Main PCB/OUTA: J3.T, R17.2
/Main PCB/OUTB: J7.T, R39.2
/Main PCB/SIGA: J4.T, R19.1
/Main PCB/SIGAP: R19.2, RV18.2, RV18.3, U2.3 (+)
/Main PCB/SIGB: J8.T, R40.1
/Main PCB/SIGBP: R40.2, RV41.2, RV41.3, U2.14 (+)
/Main PCB/VCAB_OUT: R38.2, R39.1, U2.9
GND: C1.2, C2.2, C3.2, C4.1, C5.1, C6.1, J1.S, J2.S, J3.S, J4.S, J5.S, J6.S, J7.S, J8.S, J103.3 (GND), J103.4 (GND), J103.5 (GND), J103.6 (GND), J103.7 (GND), J103.8 (GND), Q2.1 (E), Q4.1 (E), R6.2, R20.2, R22.2, R28.2, R37.2, R42.2, R44.2, R101.2, TP102.1, U2.4 (-), U2.13 (-); also elsewhere on the board
unnamed: Q1.1 (E), Q2.2 (B), R14.1
unnamed: Q2.3 (C), R15.1
unnamed: Q3.1 (E), Q4.2 (B), R34.1
unnamed: Q4.3 (C), R35.1
unnamed: R2.2, R9.2, U1.14
unnamed: R20.1, RV18.1
unnamed: R21.2, R22.1, R46.2, U2.5, U2.7
unnamed: R24.2, R31.2, U1.1
unnamed: R42.1, RV41.1
unnamed: R43.2, R44.1, R48.2, U2.10, U2.12
unnamed: R27.2, R28.1, U1.3 (+)
unnamed: R24.1, R25.2, U1.2 (-)
unnamed: R36.2, R37.1, U1.5 (+)
unnamed: R13.2, R101.1, U1.10 (+)
unnamed: R5.2, R6.1, U1.12 (+)
unnamed: R2.1, R3.2, U1.13 (-)
VCAA_OUT: J8.TN, R16.2, R17.1, U2.8

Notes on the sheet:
Hardware

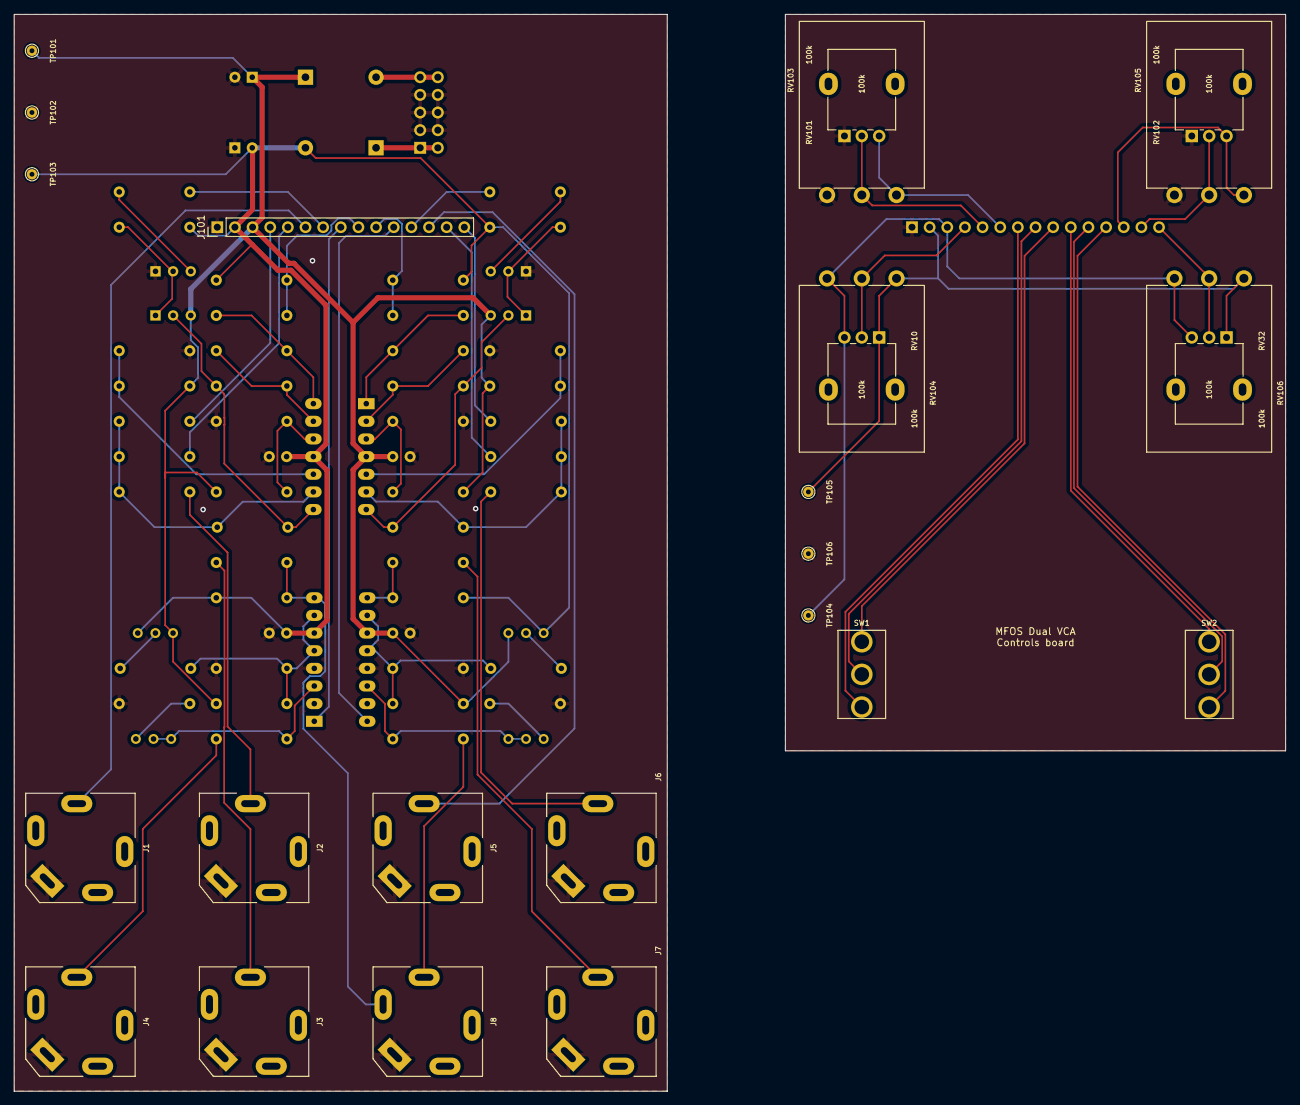
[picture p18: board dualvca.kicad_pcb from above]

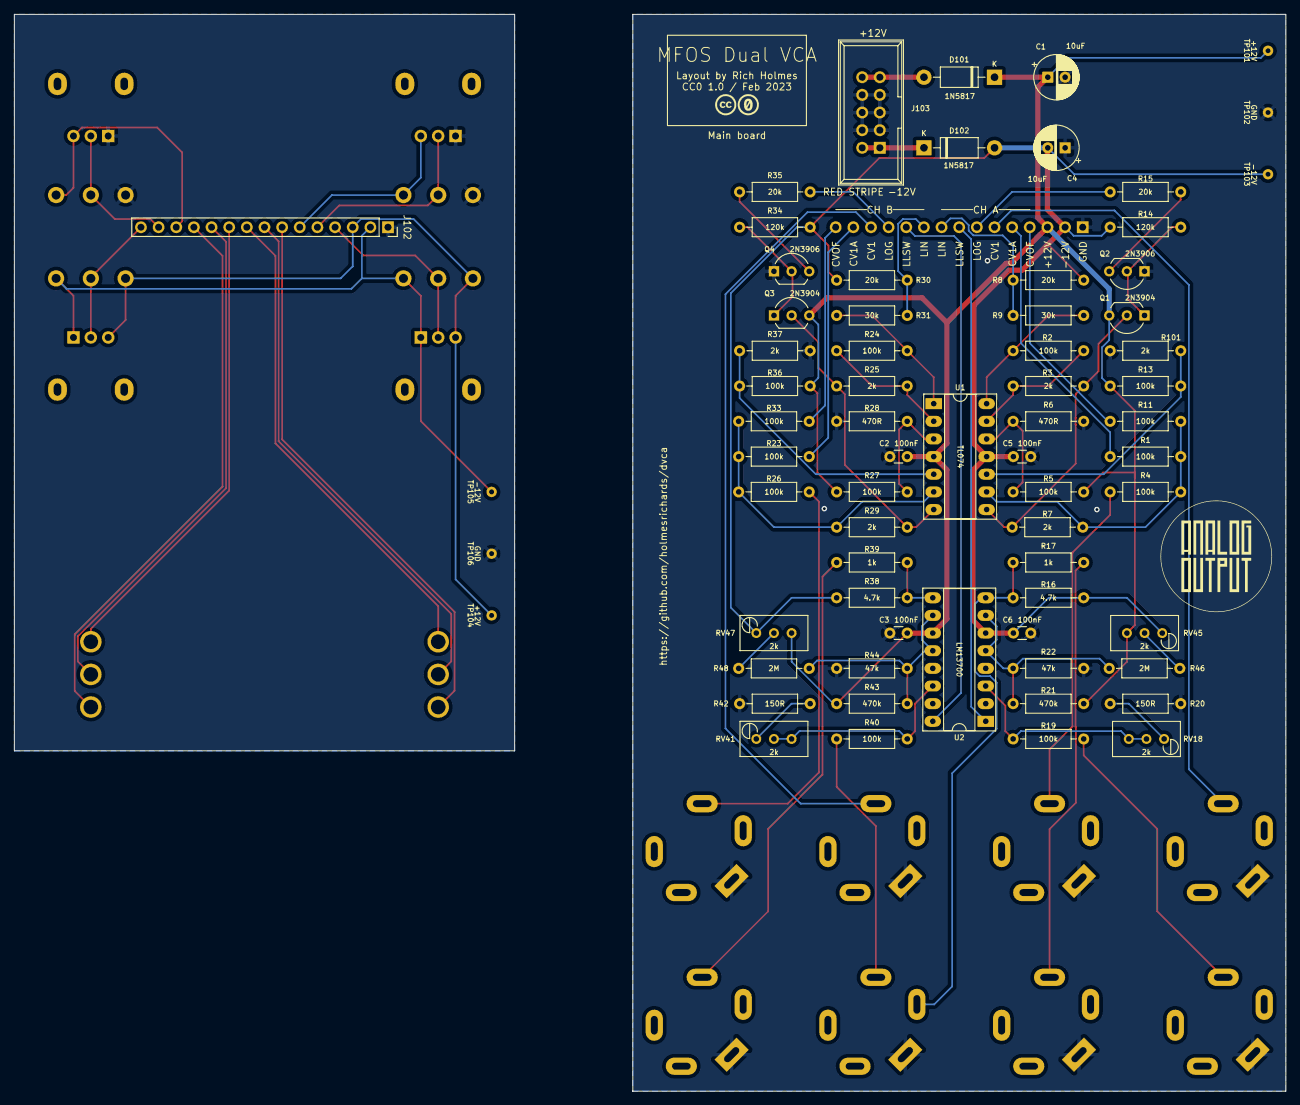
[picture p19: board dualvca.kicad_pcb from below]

Board: 2 copper layers, 94.0 x 155.0 mm, 93 parts (64 on the bottom side), 64 nets.

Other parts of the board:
TP104: +12V; TestPoint_THTPad_D1.5mm_Drill0.7mm
TP105: -12V; TestPoint_THTPad_D1.5mm_Drill0.7mm
TP106: GND; TestPoint_THTPad_D1.5mm_Drill0.7mm

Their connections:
+12V_1: TP104.1; also elsewhere on the board
-12V_1: TP105.1; also elsewhere on the board
GND1: TP106.1; also elsewhere on the board

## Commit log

2023-02-03 Initial version
    [dualvca.kicad_pcb, dualvca.kicad_sch, main.kicad_sch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]
2023-02-03 Nuke 75 mm files; better README; PDF docs
    [mfos_vca-panel-B_Cu.gbr, mfos_vca-panel-B_Mask.gbr, mfos_vca-panel-B_Paste.gbr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]
2023-02-05 KiCad 7, libraries to folder
    [dualvca.kicad_pcb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]
2023-02-11 Pre fab tweaks, Gerbers
    [dualvca.kicad_pcb, dualvca.kicad_sch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]
2023-02-15 Hardware, BOM
    [dualvca.kicad_sch, main.kicad_sch, potsw.kicad_sch]
2023-03-14 Rearrange panel labels
    [mfos_vca-panel-B_Silkscreen.gbo, mfos_vca-panel-CmtUser.gbr, mfos_vca-panel-CuBottom.gbl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]
